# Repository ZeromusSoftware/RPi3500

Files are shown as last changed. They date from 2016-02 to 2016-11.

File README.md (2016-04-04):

#[Adamant](http://adamant.ga) 

####*A small cluster of Rasperry Pi connected with Hadoop*

---
### *Because we are found of Camembert and Croissant, but Fish & Chips and Guinness too.*

1. **French** 
2. **English** [^2]

----
[^1]:**French Version**

### Qui Sommes Nous ?

Nous sommes une équipe de 4 élèves de PTSI du Lycée Jean Perrin à Marseille

 - Louis Bernon - *Génie Thermique - Conception*
 - Quentin Bergé - *Génie Electrique - Conception*
 - William Jackson - *Réseau - Données et Algorithmes Machine Learning*
 - Bastien Pederencino- *Réseau - Données et Algorithmes Machine Learning - Big Data*

### Notre Objectif

 Création d'un Data Center et Analyseur miniaturisé à l'aide de Raspberry Pi, géré à distance via une Interface Web.
 ---

### Les Domaines Abordés
--

#### Le Big Data
Notre Data Center n'est pas comme les autres, il est pourvu d'une capacité d'analyse de données rentrant dans le domaine du Big Data.

Pour de plus amples informations, rendez-vous dans la rubrique [Big Data](https://github.com/ZeromusSoftware/RPi3500/tree/master/big_data)

#### L'Interface Web
Pour interagir avec ce Data Center et étant donné qu'il est connecté à Internet, nous avons décidé de mettre en place une Interface Web qui sera présente sur notre site [Adamant](http://adamant.ga).  
Cela nous permettra de lui envoyer des commandes, de récupérer des résultats (etc). Maintes applications seront possibles.

Pour de plus amples informations, rendez-vous dans la rubrique [API Web](https://github.com/ZeromusSoftware/RPi3500/tree/master/apiweb)

#### Le Réseau

Nos différents RPi sont connectés entre eux et forment ainsi un Réseau. Il sert ainsi à l'interaction et la communication entre ces différents composants.

####Machine Learning
Le Machine Learning est la capacité d'apprentissage des algorithmes sur la base de connaissances acquises.   
Ces nouveaux algorithmes peuvent alors solver des problèmes autrefois qualifiés de complexes.
Nous travaillons alors sur la façon de mettre en place ceci dans notre Data Center.

#### Génie Thermique
Le Système comporte des éléments qui sont susceptibles de chauffer et une chaleur excessive les endommageraient prématurement.

 Alors nous nous devons de les maintenir à température acceptable, pour ce faire nous utiliserons des ventilateurs récupérés de PC et des dissipateurs thermique conçus expressement pour les RPis.
 
 Pour de plus amples informations, rendez vous dans la rubrique [Heat Control](https://github.com/ZeromusSoftware/RPi3500/tree/master/heat_control)

#### Génie Electrique
Nous devons alimenter notre Data center conformément aux caractéristiques des composants présents tels les RPi2 et RPiB+ ainsi que le Switch Ethernet et le système de refroidissement.

Aussi ce Data Center doit pouvoir continuer à fonctionner en cas de coupure prolongée de l'alimentation du réseau électrique, c'est pourquoi il sera doté de batteries.

Pour de plus amples informations, rendez-vous dans la rubrique [Power Supply](https://github.com/ZeromusSoftware/RPi3500/tree/master/power_supply)

#### Conception
 Nous concevons notre Data Center miniaturisé dans lequel sera présent tout notre système. Il sera réalisé de contreplaqué okoumé et comprendra une surface transparente en plexiglass. Sa forme peut-être apparentée à celle d'une tour de PC.
 
 Pour de plus amples informations, rendez vous dans la rubrique [Box Architecture](https://github.com/ZeromusSoftware/RPi3500/tree/master/Box%20architecture) 
 
--

### Technologies Utilisées
* [Raspberry Pi](https://www.raspberrypi.org)
* [Python](https://www.python.org)
* [Raspbian](http://raspbian-france.fr)
* [Hadoop](http://hadoop.apache.org)
* [Propulse](http://www.ppulse.fr/#!)
* Git
* [LaTeX](https://www.latex-project.org)
* [SolidWorks](http://www.solidworks.fr)
* [Fritzing](http://fritzing.org/home/)
* Iron Hawk
* [PHP/MySQL](http://php.net) - [HTML5/CSS3](https://www.w3.org/html/)

--

### Contacts

* Mail : zermomus.software@gmail.com
* [Adamant] (http://adamant.ga)
* [Zeromus Software] (bpedernecino.legtux.org)
* [Bastien Pederencino](https://www.linkedin.com/in/bpederencino?authType=name&authToken=ZWAr&trk=prof-proj-cc-name)
* [Quentin Bergé](http://twitter.com/bergequentin)

>Google and Harvard Business Review said "Data Scientist: The Sexiest Job of the 21st Century"

------
English [^3]

[^2]: To English Version Click on "2"

[^3]: English

--

###About Us

We are a team compose by 4 students from Jean Perrin's preparatory PTSI class in Marseille.

- Louis Bernon - *Thermal Engineering - Conception*
- Quentin Bergé - *Electrical Engineering - Conception*
- William Jackson - *Network - Data and Machine Learning Algorithms*
- Bastien Pederencino- *Network - Data and Machine Learning Algorithms - Big Data*

### Our Objective

To make a Data Center in miniature with Raspberry Pi, remotely managed by a web interface.

---

### Domains Touched

--

#### Big Data

Our Data Center can analyze data, in accord with Big Data domains.

For more informations, please consult [Big Data](https://github.com/ZeromusSoftware/RPi3500/tree/master/big_data) 

#### The Web Interface

To interact with this Data Center, we decide to set up a Web Interface on our website [Adamant](http://adamant.ga). It enables to sent instructions and retrieve results (etc). Many usage can be possible.

For more informations, please consult [API Web](https://github.com/ZeromusSoftware/RPi3500/tree/master/apiweb)

#### The Network

Ours Raspberry Pi are interconnected and make a Network. It serves the communication between these differents features.

#### Machine Learning 

Machine Learning Algorithms are engineered with a learning capacity. It enables to solve complex issues.
We work to make our Data Center compatible with these algorithms.

#### Thermal Engineering

Our System countains active features as RPi, they can overheat, and being damaged. Therefore, we have to survey them, and keep it under review. We use fans and heatsink.

For more information, please consult [Heat Control](https://github.com/ZeromusSoftware/RPi3500/tree/master/heat_control)

#### Electrical Engineering

We have to provide an electric alimentation to all of Data Center's features as RPi2, RPi B+, Ethernet Switch and fans.
Also, this system need to stay in working order even in a power failure case, therefore we can use battery.

For more information, please consult [Power Supply](https://github.com/ZeromusSoftware/RPi3500/tree/master/power_supply)  

#### Conception

We build our miniaturize Data Center with plywood panel and plexiglass. His shape can be assimilate as a tower PC.

For more informations, please consult [Box Architecture](https://github.com/ZeromusSoftware/RPi3500/tree/master/Box%20architecture) 

--

###Employed Technologies

* [Raspberry Pi](https://www.raspberrypi.org)
* [Python](https://www.python.org)
* [Raspbian](http://raspbian-france.fr)
* [Hadoop](http://hadoop.apache.org)
* [Propulse](http://www.ppulse.fr/#!)
* Git
* [LaTeX](https://www.latex-project.org)
* [SolidWorks](http://www.solidworks.fr)
* [Fritzing](http://fritzing.org/home/)
* Iron Hawk
* [PHP/MySQL](http://php.net) - [HTML5/CSS3](https://www.w3.org/html/)

--

### Contacts

* Mail : zermomus.software@gmail.com
* [Adamant] (http://adamant.ga)
* [Zeromus Software] (bpedernecino.legtux.org)
* [Bastien Pederencino](https://www.linkedin.com/in/bpederencino?authType=name&authToken=ZWAr&trk=prof-proj-cc-name)
* [Quentin Bergé](http://twitter.com/bergequentin)

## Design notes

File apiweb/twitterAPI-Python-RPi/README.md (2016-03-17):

#[Adamant](http://adamant.ga) 

## A system to link RaspberryPi with Twitter's API thanks to Python
   
 * @author   William Jackson
 * @license  GNU General Public License 2
 * @version  0.1.0
 * @link     http://github.com/ZeromusSoftware/RPi3500

--

### Issues to fix

* (Try and tell us)

--

### Contacts

* Mail : zermomus.software@gmail.com

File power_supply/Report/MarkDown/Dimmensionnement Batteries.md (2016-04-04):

#Dimmensionnement Batteries
---
###Préambule

Pour parer à l'éventualité de la coupure de courant EDF, il nous faut une seconde source d'alimentation afin d'assurer le fonctionnement en continu de notre Data Center. Nous planchons, comme cité [précedemment](https://github.com/ZeromusSoftware/RPi3500/blob/master/power_supply/Report/MarkDown/In%20Case%20Of%20Emergency.md), sur une autonomie de 3h soit 180 minutes.

###Choix des Batteries

Nous comptons utiliser des batteries Li-Ion ou Li-Po, très couramment utilisées dans les appareils électronique portatif. Néanmoins ces batteries sont exigeantes, il faudra les surveiller constamment en particulier lors des phases de recharge et de décharge.

Puisque nous utilisons deux circuits de deux tensions différentes, nous utiliserons deux "piles".

* l'une délivrant une tension de 5V
* l'autre délivrant une tension de 12V

###Sous Tension de 5V

Sous cette tension, nous alimenterons les 4 Raspberry Pi 2 et le Raspberry Pi B+.
Au cours de nos tests, la consommation maximale relevé à été de 0,55 Ampères.  

En prenant une marge de sécurité alors de 0,25 Ampères :

* 0,8 A x 5 RPi = **4 A**

Or nous souhaitons 3h d'autonomie :

 * Q = I x T 
 * 4 A x 3h = **12 A.h**

 Il nous faudra alors une batterie avec une capacité de 12 A.h et capable de délivrer un courant superieur à 4 A sous une tension continue de 5V.

###Sous Tension de 12V

Sous cette tension, nous alimenterons les 4 ventilateurs et le switch ethernet.

Selon les caractéristiques constructeurs, sous cette tension la batterie devra fournir un courant d'environ 2,5 Ampères en s'imposant une petite marge de sécurité de 0,25 Ampères.

Or nous souhaitons 3h d'autonomie aussi :

* Q = I x T
* 2,5 x 3 = **7,5 A.h**

	Il nous faudra alors une capacité de 7,5 A.h sous cette batterie délivrant une tension continue de 12V qui doit être capable de délivrer un courant de 2,5 A.

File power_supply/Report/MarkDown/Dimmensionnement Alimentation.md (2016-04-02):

#Dimmensionnement Alimentation
---

###Composition du Système

Notre Data Center se compose de plusieurs éléments consommant de l'énergie :

* 4 Raspberry Pi 2
* 1 Raspberry Pi B+
* 1 Switch Ethernet
* 4 Ventilateurs

###Spécifications Constructeurs
Pour la partie Réseau et Informatique

* Raspberry Pi 2 : Il doit être alimenté en 5V avec un courant minimum de 1,8 A
* Raspberry Pi B+ : Il doit être alimenté en 5V avec un courant minimum de 0,7 A
* Switch Ethernet Netgear GS608 : Il doit être alimenté en 12V et consommme au maximum 0,5 A 

Pour la partie Refroidissement :

* 2 ventilateurs consommant 0,45 A chacun et alimenté en 12V
* 1 ventilateur consommant 0,7 A et alimenté en 12V
* 1 ventilateur consommant 0,16 A et alimenté en 12V

###Courant Nécéssaire

Nous pouvons établir le courant nécéssaire pour l'alimentation du système 

* Sur le 5V : 4 x 1,8 + 0,7 = **7,9A**
* Sur le 12V : 0,5 + 2 x 0,45 + 0,7 + 0,16 = **2,26A**

###Solution Apportée
 Nous avons récupéré une alimentation de PC 500W. Ces générateurs sont destinés à alimenter des composants éléctroniques fragiles, elle sera donc particulièrement bien adapté à l'alimentation de notre Data Center.
 
 De plus selon ses caractéristiques, elle peut fournir :
 
 * Sur le 5V : **36A**
 * Sur le 12V : **20A**

Elle est donc largement dimmensionnée pour notre système et lui permettra de nombreuses évolutions.

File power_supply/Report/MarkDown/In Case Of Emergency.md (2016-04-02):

#In Case Of Emergency
----
###Rupture d'Alimentation

Dans le cadre de l’alimentation du Data Center, il est nécessaire de se parer à toutes les situations. La pire étant celle d’une rupture d’alimentation du réseau EDF qui nous alimente par une tension de 230V et 50Hz.

Ainsi, notre Data Center doit pouvoir fonctionner sans interruption et ce normalement, pendant une panne d’électricité provenant de l’extérieur de l’enceinte. Alors nous devons le pourvoir d’une capacité de stockage d’énergie grâce à des batteries.

###Durée Moyenne d'une Panne Electrique

D’abord nous nous sommes renseignés sur la durée moyenne d’une panne de courant : Elle est d’environ 87,6 min entre 2010 et 2014 (dernières données disponibles selon EDF).

![Coupure EDF] (http://img15.hostingpics.net/pics/350350CoupureEDF.png "coupure edf")

###Durée d'Autonomie

Il est alors certain que nous devons avoir une durée supérieur et largement supérieur même pour parer à une éventuelle panne prolongée d’alimentation.

Nous plancherons ainsi sur une panne de 3H ce qui correspond à 180 min d’autonomie.

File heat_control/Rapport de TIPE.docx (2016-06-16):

Rapport de TIPE

Cette partie de la mise en place d’un data center vise au contrôle de la température des composants. Pour cela nous avons choisi un système de ventilation par soucis de praticité.

Nous avons mesuré la température des composants puis avons testé différentes dispositions des ventilateurs afin de trouver celle qui permettait de refroidir au mieux le boîtier. Après avoir obtenu ces « meilleures » dispositions, il faut trouver un compromis entre un bon refroidissement et les désavantages qu’impliquent ce système (consommation, bruit..).

Une fois le compromis trouvé, nous pourrons finir la construction du boîtier.

Mots-clés

Refroidissement – Ventilateurs – Raspberry pis – Empirique - Simulations

Cooling – Fans – Raspberry pis – Tests - Simulations

Bibliographie

-Site officiel de Fluke (http://www.fluke.com/fluke/frfr/thermographie/fluke-tis20.htm?pid=79860)

-Site d’information sur les Raspberry pis (http://the-raspberry.com/)

Remerciements

Je remercie l’équipe pédagogique qui nous a aidés et conseillés tout au long de l’année.

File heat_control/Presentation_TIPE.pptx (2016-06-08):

## TIPE : Mise en place d’un Data Center

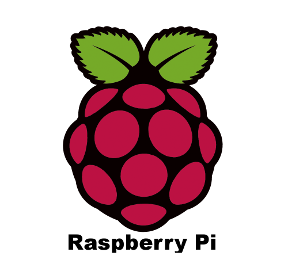
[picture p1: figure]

Louis Bernon – PTSI2

## Sommaire

I. Contrôle de la température
  1. Éléments à refroidir
  2. Mesures
  3. Moyens de refroidissement
  4. Dimensionnement
  5. Continuation
II. Conception du boitier
  1. Plans
  2. Dimensionnement
  3. Construction

## Contrôle de la température

Éléments à refroidir

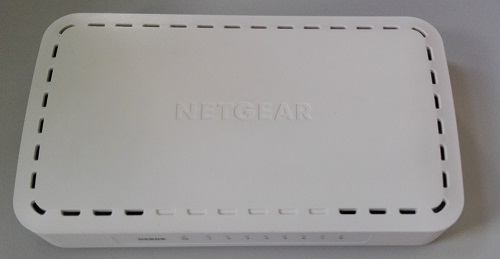
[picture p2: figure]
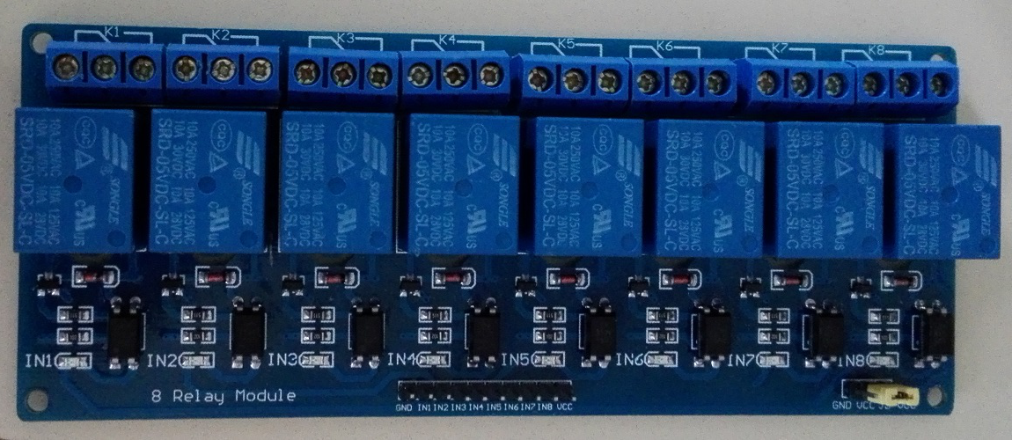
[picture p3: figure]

Switch Ethernet

Relais

Raspberry pi

## Mesures

On a simulé l’utilisation des Raspberrys grâce à une commande intégrée qui fait augmenter par paliers de 25% la charge du CPU
On a ensuite relevé les températures des cartes grâce à une caméra thermique Fluke lors de leur utilisation sans boîtier

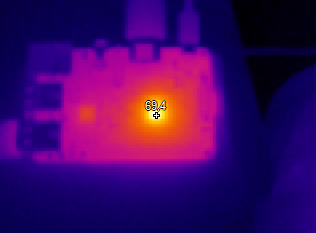
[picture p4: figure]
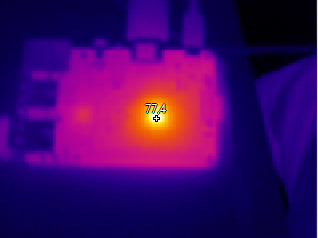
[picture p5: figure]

Utilisation optimale : température ambiante
La température est donc trop élevée pour une utilisation à plein temps

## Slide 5

Utilisation de radiateurs prévus spécialement pour les Raspberrys

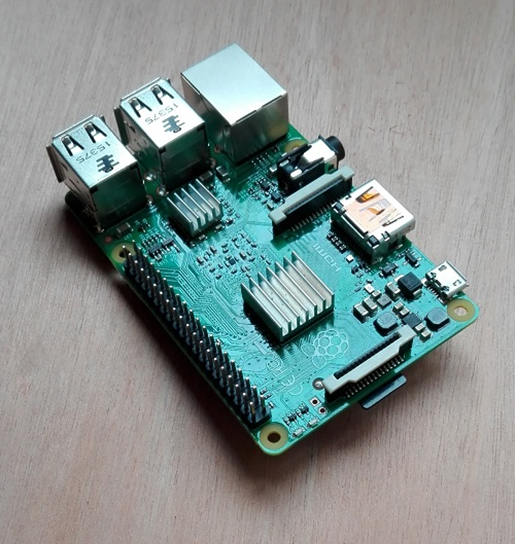
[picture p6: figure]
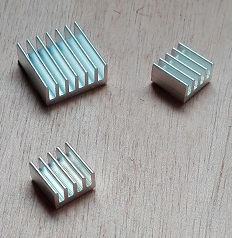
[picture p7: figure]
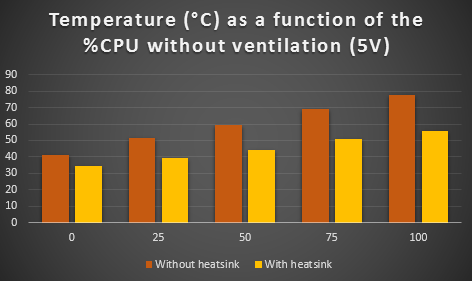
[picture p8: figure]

On perd jusqu’à 20°C avec les radiateurs mais la
Température est toujours trop élevée

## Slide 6

Nous avons donc ventilé les Raspberry et repris les températures pour différentes charges du CPU

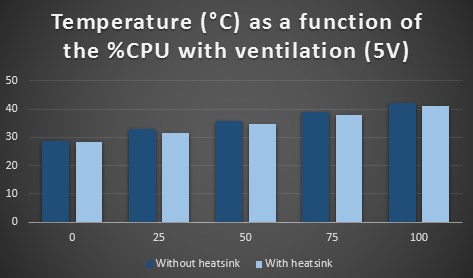
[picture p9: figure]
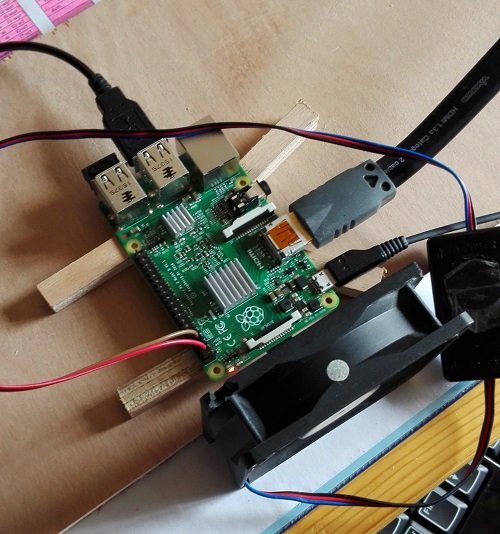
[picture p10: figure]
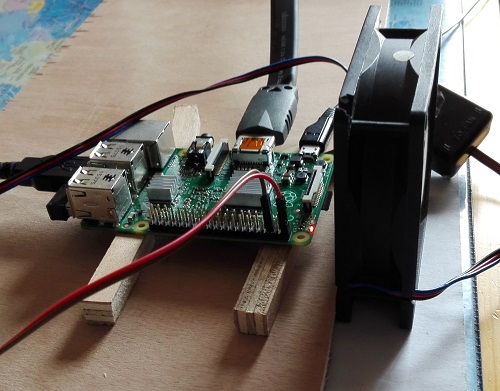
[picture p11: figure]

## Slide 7

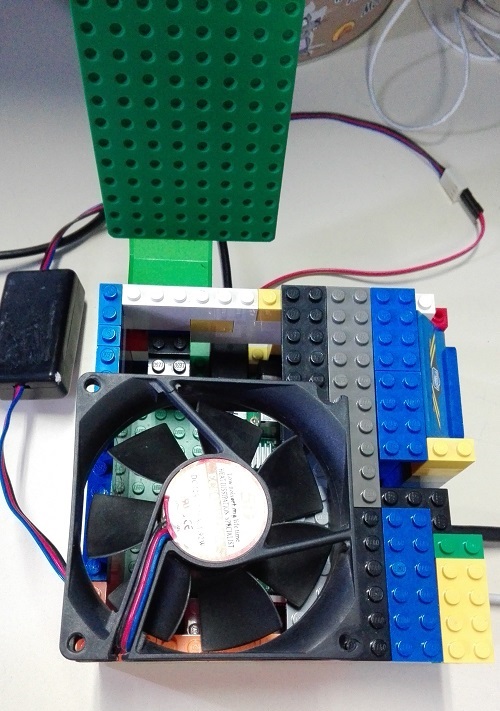
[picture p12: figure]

Utilisation finale des Raspberry pi dans un boîtier
On a donc fait les mêmes tests mais dans un boîtier

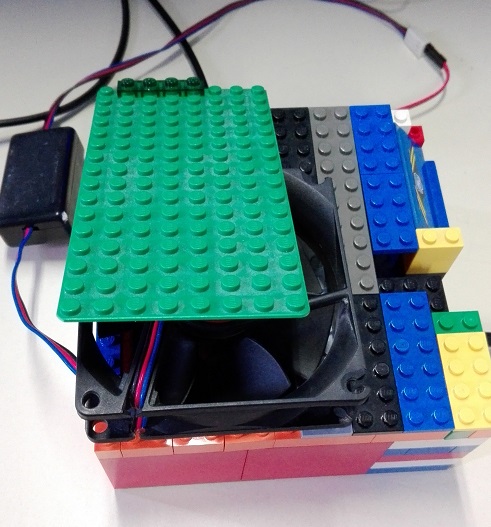
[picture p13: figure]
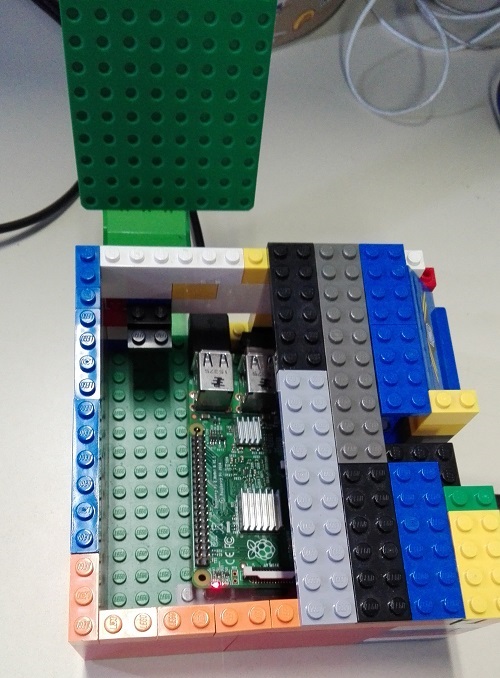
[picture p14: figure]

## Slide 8

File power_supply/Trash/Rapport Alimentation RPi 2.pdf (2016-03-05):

Quentin Bergé | 4 mars 2016

Préambule
Suite à nos tests de la semaine dernière, nous avons continué nos recherches et sommes parvenus à notre but final ! Nous avons pousser nos bêtes dans leurs derniers retranchement, et cela afin de mesurer la consommation de nos Rapsberry Pi 2

Principe de Mesure
Nous avons donc effectuer un Stress Test, communément appelé ainsi. Cela consiste en utilisant à 100% la puissance fourni par nos petits RPi2. Pendant ce temps, nous avons mesuré la consommation électrique de ces petites bébêtes.

Mode Opératoire Détaillé
A l’aide d’une ligne de commande entré dans le terminal des Pi sous raspbian, nous pouvons augmenter par palier de 25% la charge du CPU (Processeur). Dans ce cas nous avons pu effectué nos mesures à l’aide d’un ampèremètre branché en série du circuit d’alimentation.
En parallèle nous refroidissions aussi le processeur à l’aide d’un ventilateur, afin de ne pas le faire surchauffer, ce qui pourrait l’endommager prématurément.

Mesures

Charge CPU | Consommation (A) | Température (°C)
0 % | 0,260 | 22,1
25 % | 0,283 | 25
50 % | 0,318 | 26,1
75 % | 0,355 | 28,2
100 % | 0,395 | 29,3
Consommation RPi2 | 1

# STRESS TEST

### Consommation Raspberry Pi 2

Quentin Bergé | 4 mars 2016

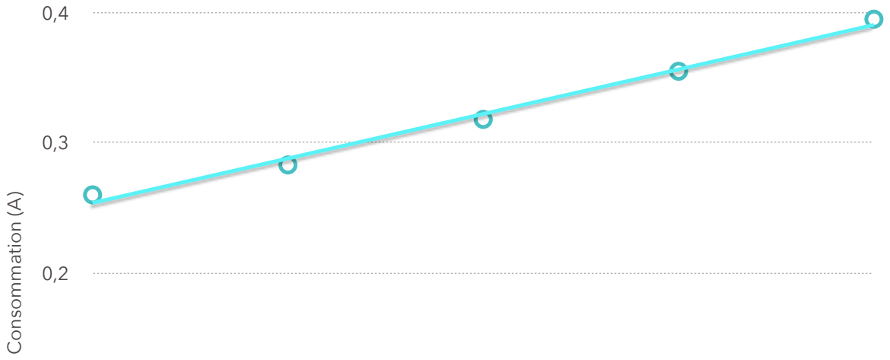
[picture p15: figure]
Consommation (A)

Consommation RPi2 | 2

Consommation Electrique en fonction Charge Processeur

0

0,1

Charge CPU (%)

0 | 0,25 | 0,5 | 0,75 | 1

Analyse Des Mesures
Cela est pour le moins déconcertant mais le RPi2 ne consomme pas plus de 0,4 A contrairement aux caractéristiques données par la Raspberry Pi Foundation qui préconise une alimentation de 1,8 A minimum.
Néanmoins ce qui est positif pour nous c’est qu’ainsi, le courant d’alimentation ne devra point être très important sur l’ensemble du système. Ainsi nous aurons besoin que de cables dimensionnées pour faire passer tout au plus 1 A sous 5V. Ce qui implique un coût bien moindre et donc largement maitrisé.

Conclusion
Nous avons ainsi pu conclure sur la consommation bien plus faible qu’indiqué pour nos petits RPi et ce même à pleine puissance, Alors notre alimentation pourra aisément alimenter l’ensemble de notre sytème et bien plus !

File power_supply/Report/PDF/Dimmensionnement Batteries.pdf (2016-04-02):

Pour parer à l'éventualité de la coupure de courant EDF, il nous faut une seconde source d'alimentation afin d'assurer le fonctionnement en continu de notre Data Center. Nous planchons, comme cité précedemment, (https://github.com/ZeromusSoftware/RPi3500/blob/master/power_supply/Report/MarkDown/In%20Case%20Of%20Emergency.md) sur une autonomie de 3h soit 180 minutes.

Nous comptons utiliser des batteries Li-Ion ou Li-Po, très couramment utilisées dans les appareils électronique portatif. Néanmoins ces batteries sont exigeantes, il faudra les surveiller constamment en particulier lors des phases de recharge et de décharge.

Puisque nous utilisons deux circuits de deux tensions différentes, nous utiliserons deux "piles".

l'une délivrant une tension de 5V
l'autre délivrant une tension de 12V

Sous cette tension, nous alimenterons les 4 Raspberry Pi 2 et le Raspberry Pi B+. Au cours de nos tests, la consommation maximale relevé à été de 0,5 Ampères.

En prenant une marge de sécurité alors de 0,1 Ampère :

0,6 A * 5 RPi = 3,5 A

Or nous souhaitons 3h d'autonomie :

Q = I*T
3,5 A * 3h = 10,5 A.h

Il nous faudra alors une batterie avec une capacité de 10,5 A.h et capable de délivrer un courant superieur à 3,5 A sous une tension continue de 5V.

Sous cette tension, nous alimenterons les 4 ventilateurs et le switch ethernet.

Selon les caractéristiques constructeurs, sous cette tension la batterie devra fournir un courant d'environ

# Dimmensionnement Batteries

## Préambule

## Choix des Batteries

## Sous Tension de 5V

## Sous Tension de 12V

2,5 Ampères en s'imposant une petite marge de sécurité de 0,25 Ampères.

Or nous souhaitons 3h d'autonomie aussi :

Q = I*T
2,5 * 3 = 7,5 A.h

Il nous faudra alors une capacité de 7,5 A.h sous cette batterie délivrant une tension continue de 12V qui doit être capable de délivrer un courant de 2,5 A.

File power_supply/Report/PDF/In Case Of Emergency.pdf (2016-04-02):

Dans le cadre de l’alimentation du Data Center, il est nécessaire de se parer à toutes les situations. La pire étant celle d’une rupture d’alimentation du réseau EDF qui nous alimente par une tension de 230V et 50Hz.

Ainsi, notre Data Center doit pouvoir fonctionner sans interruption et ce normalement, pendant une panne d’électricité provenant de l’extérieur de l’enceinte. Alors nous devons le pourvoir d’une capacité de stockage d’énergie grâce à des batteries.

D’abord nous nous sommes renseignés sur la durée moyenne d’une panne de courant : Elle est d’environ 87,6 min entre 2010 et 2014 (dernières données disponibles selon EDF).

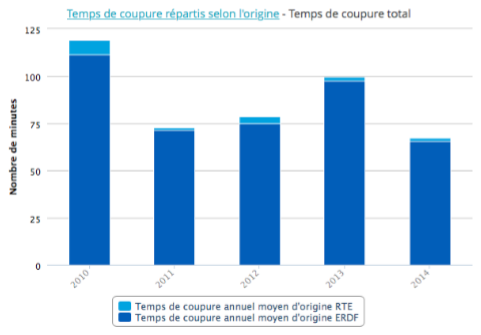
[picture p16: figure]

Il est alors certain que nous devons avoir une durée supérieur et largement supérieur même pour parer à une éventuelle panne prolongée d’alimentation.

Nous plancherons ainsi sur une panne de 3H ce qui correspond à 180 min d’autonomie.

# In Case Of Emergency

## Rupture d'Alimentation

## Durée Moyenne d'une Panne Electrique

## Durée d'Autonomie

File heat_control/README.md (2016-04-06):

# Welcome in Heat Control

This part of the **Adamant** project is dedicated to the refreshment of the box that will contain every part of this project.
Here will be exposed our equipment and our progress in the achievement of this part.

We'll have to run a lot of tests in order to determine the best and the greenest way to refresh the box.

----------------

If you're interested with the box I talked about, you can see it [here](<https://github.com/ZeromusSoftware/RPi3500/tree/master/box_architecture>)

----------------
**If you have some suggestions to make, contact me at [Louis Bernon](mailto:loulou.bernon@gmail.com)**

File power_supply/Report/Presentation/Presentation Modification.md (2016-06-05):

#Changement pour Présentation

###Mesures
* Détailler le protocole de mesure
* Parler du redresseur de l'alimentation
* Parler de l'abaissement de tension 
* Faire apparaitre les bornes sur la mesures COM et A

###Schémas
* Détailler plus les schémas
* Montrer de meilleures photos

###Durée
* Faire plus concis selon Minetti, on dépasse trop là durée

###Conclusion
* Elaborer une conclusion à proprement parler sur le respects de la satisfaction du critère d'alimentation

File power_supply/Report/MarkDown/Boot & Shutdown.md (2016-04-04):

#Boot & Shutdown
---

###Préambule

Afin de bien dimmensionner nos batteries et notre alimentation, nous recherchons toujours la consommation maximale de nos Raspberry. Ainsi, c'est dans ce cadre que s'inscrit ce rapport. Nous avons alors eu l'idée de mesurer la consommation de nos mini-ordinateurs dans des phases critiques.

###Principe de Mesure

La phase d'allumage est critique au sens où le Pi se doit de disposer de tout sa puissance afin de se mettre en route, de tester le fonctionnement de tout ses composants. C'est ici que l'on pourrait atteindre un pic de consommation.	

La phase d'extinction est quant à elle importante afin de constater la consommation du Pi quand il est éteint.

Nous mesurerons alors la consommation de notre Pi lors de ces deux phases.

###Mode Opératoire Détaillé

Nous brancherons en série du circuit d'alimentation un Ampèremetre qui nous afficheras alors la consommation instantanée du RPi.

Nous restranscrirons toutes nos mesures sous forme de graphiques que nous analyserons.

###Mesures
--

1. Démarrage

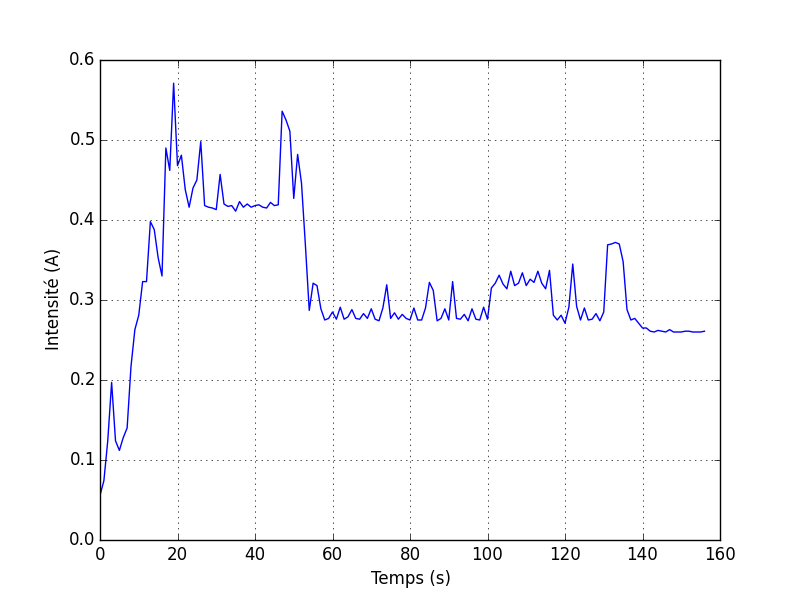
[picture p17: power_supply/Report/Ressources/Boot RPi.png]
Boot
 

2. Extinction

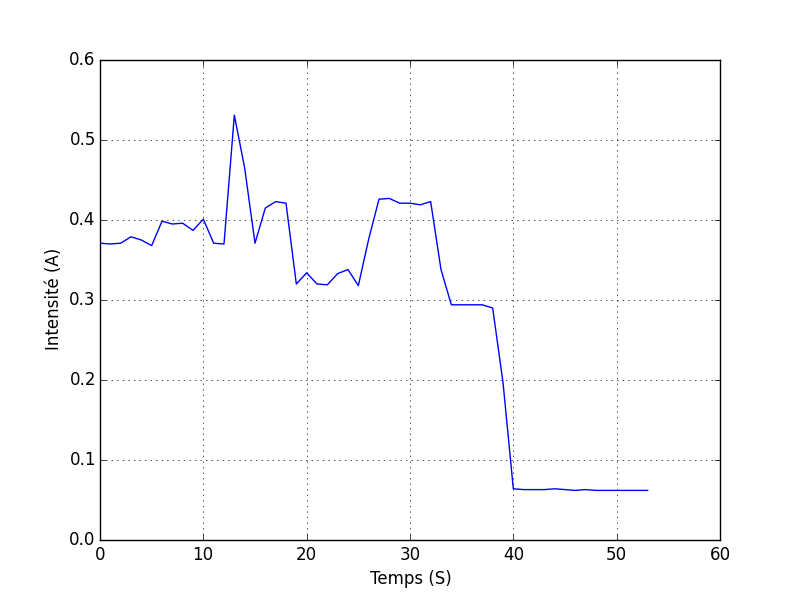
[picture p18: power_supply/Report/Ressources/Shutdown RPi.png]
Shutdown


###Analyse des Courbes
--

#####Démarrage

* Nous pouvons d'abord voir un pic à 0,58 Ampères ce qui est la plus haute valeur constatée jusqu'à présent.
* La phase de démarrage dure, avant que tout soit prêt à fonctionner, environ une minute ce qui correspond à la fin du dernier pic de consommation sur la courbe.
* Aussi nous pouvons noter la stabilisation de la consommation au bout d'environ 145 secondes.

#####Extinction

* La phase d'extinction dure environ 40 secondes.
* Nous pouvons observer un pic à plus de 0,530 Ampères, ensuite le courant décroit à nouveau puis un nouveau pic à 10 secondes de la fin de la phase puis presque le silence radio, le Pi à rendu son dernier souffle.
* En étant éteint, notre Raspberry consomme tout de même près de 60 mA ce qui parait assez élevé.

###Conclusion

Le pic de consommation confirme alors nos hypothèses, le RPi consomme le plus de courant durant sa phase d'allumage. Il faudra alors calquer nos dimmensionnement de nos alimentations sur ces résultats.
	
Aussi il paraît encore et toujours très peu gourmand en énergie, moins de 3 Watts de puissance consommé ce qui en constitue un parfait équipement pour rester allumer en permanence tel un Data Center.

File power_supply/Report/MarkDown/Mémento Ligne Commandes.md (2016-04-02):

#Mémento Ligne Commandes

* Augmenter Cadence CPU /25%

		sudo yes >/dev/null &
	
* Revenir à la Normale

		sudo killall yes
		
* Connaître Température CPU

		/opt/vc/bin/vcgencmd measure_temp

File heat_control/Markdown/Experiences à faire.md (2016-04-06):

# Mesure de la température

Afin de connaître la quantité de chaleur à refroidir, nous avons plusieurs tests à effectuer : 

* Mesure de la chaleur dégagée par un RPi à l'air libre avec/sans radiateur et avec/sans ventilation

* Mesure de la chaleur dégagée par un RPi dans un espace presque fermé avec/sans radiateur et avec/sans ventilation

* Mesure de la chaleur dégagée par plusieurs RPi dans un espace fermé de volume similaire à celui du boîtier final

* Test de différentes dispositions (placement des RPi entre eux, ventilateur...) afin de trouver la plus efficace et la plus écologique)

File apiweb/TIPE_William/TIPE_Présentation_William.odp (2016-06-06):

## Présentation TIPE

William Jackson

## Contexte & Exigences

Dans un projet de mise en place d'un mini data center portatif, on souhaite pouvoir intéragir avec l'ensemble à distance pour pouvoir controler le bon fonctionnement ou intervenir en cas de soucis.

Requirement Diagram

I – Le datacenter doit etre portable

II – Envoi de commandes avec

temps d'attente de réponse court (10s maxi)

III – Permet la visualisation de l'état du système :

composants allumés/éteints, température environnante

## Problématique

## Grands Axes

Comment communiquer à distance avec un data center portable ?

A – Le mode de communication

1) Le problème du serveur web

2) Les solutions envisagées

2) La solution Twitter

B – La communication côté site

1) l'IHM

2) la réception des messages

3) l'envoi des messages

C – La communication côté data center

1) la réception des messages

2) traitement des messages

3) l'intéraction avec les composants

## A – Le mode de communication

Il faut trouver un moyen de communiquer avec la machine

Diagramme d'utilisateur ?

## 1) Le problème de serveur web

A – Le mode de communication

## 2) Les solutions envisagées

A – Le mode de communication

## 3) La solution Twitter

A – Le mode de communication

## B – La communication côté site

## 1) L'Interface Homme Machine

B – La communication côté site

## 2) Le traitement des messages

B – La communication côté site

## 3) L'envoi des messages

B – La communication côté site

## C - La communication côté data center

## 1) La réception des messages

B – La communication côté data center

## 2) Le traitement des messages

B – La communication côté data center

## 3) L'intéraction avec les composants

B – La communication côté data center

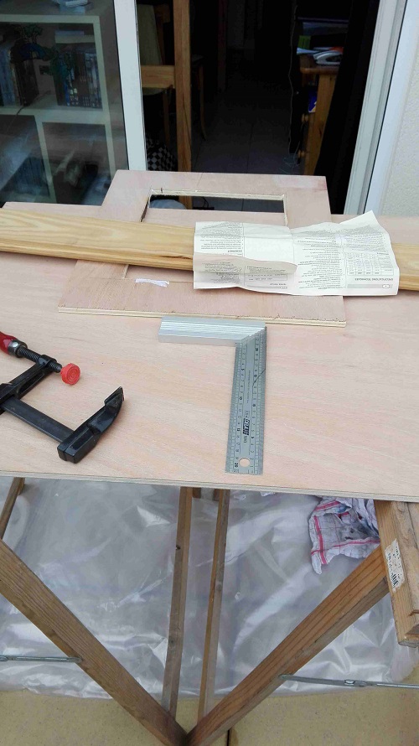
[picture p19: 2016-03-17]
box_architecture/Pictures/Cutting.jpg

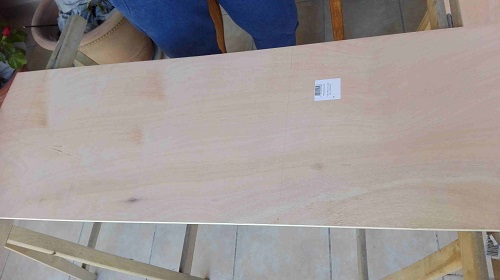
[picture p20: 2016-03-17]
box_architecture/Pictures/Plank2.jpg

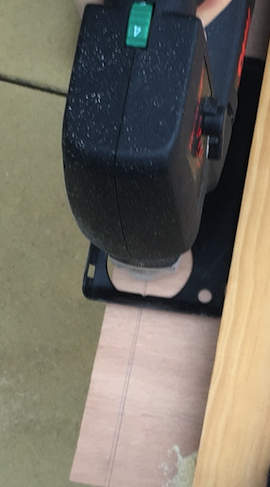
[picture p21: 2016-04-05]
box_architecture/Pictures/Scie Sauteuse en Action.png

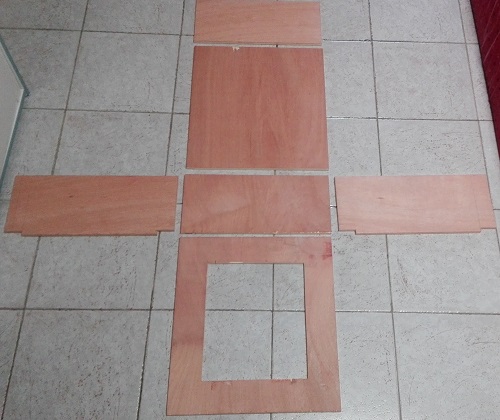
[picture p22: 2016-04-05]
box_architecture/Pictures/Planks.jpg

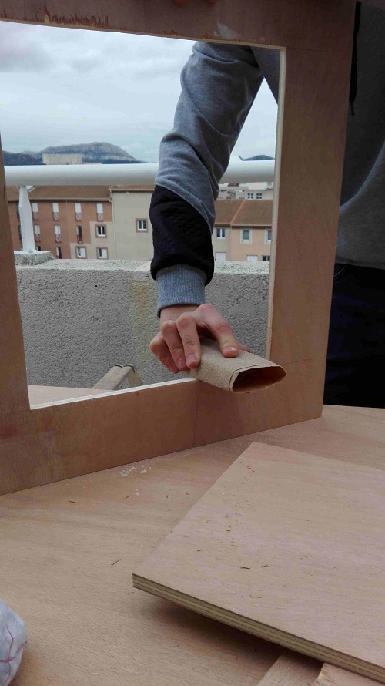
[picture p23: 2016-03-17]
box_architecture/Pictures/sanding.jpg

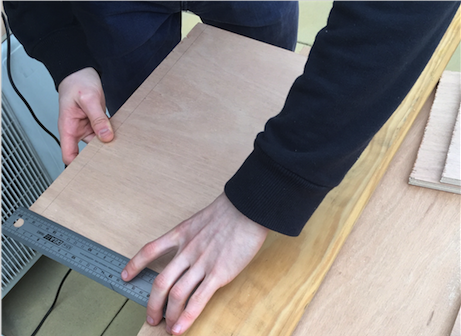
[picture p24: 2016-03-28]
box_architecture/Pictures/Mesure ecartement Equerre.png

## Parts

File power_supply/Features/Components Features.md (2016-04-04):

# Caractéristiques Composants
---

###Raspberry Pi

| | Model B+ | Model 2B |
|:---|---|---:|
| SoC | Broadcom BCM2835 | Broadcom BCM2836 |
| CPU |700 MHz ARM11 Single Core |900 Mhz ARM Cortex-A7 Quadri Core|
| GPU | Broadcom VideoCore IV  | Broadcom VideoCore IV |
| SDRAM | 512 Mo | 1 Go |
|Nominal Power | 3 W (600mA) | 4 W (800mA) |

###Switch Netgear
| Model | GS608 |
|:---:|:---:|
|Consommation Max|4,32 W|
|T° Fonctionnement Max| 40°C|

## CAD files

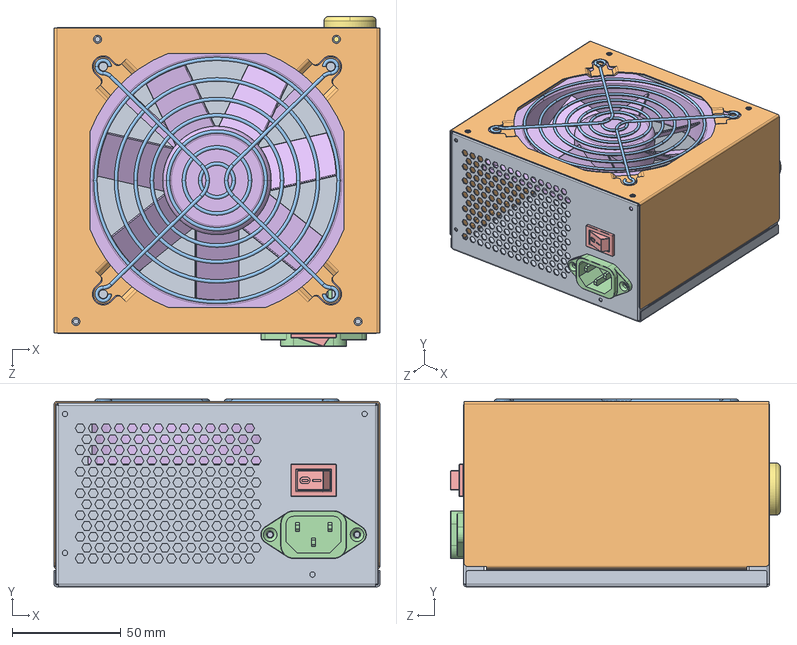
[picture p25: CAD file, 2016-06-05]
box_architecture/Modeler Solid Works/Boite 1st Jet/Models Utils/ATX Power Supply v1.0.SLDASM
150.0 x 86.4 x 152.0 mm
Box v1.0 - ATX Power Supply
Cover v1.0 - ATX Power Supply
Grelha Prot Vent 120
IEC Plug
Switch on-off
Ventax 119x119x26
Casq

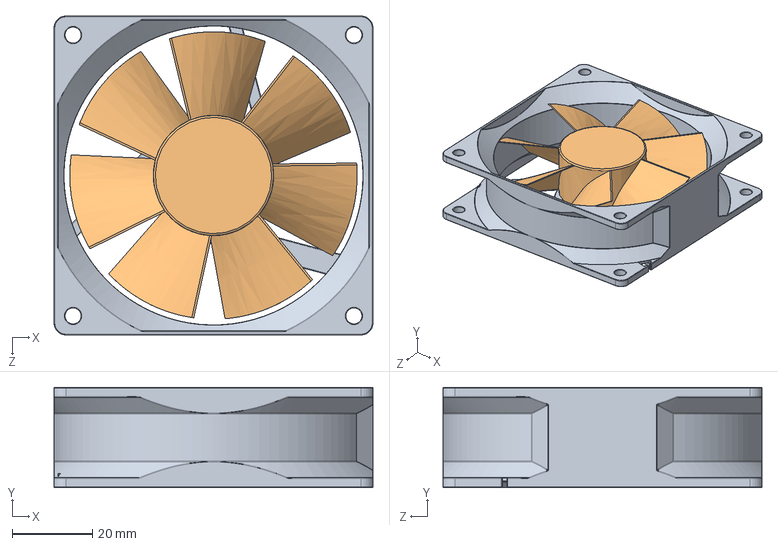
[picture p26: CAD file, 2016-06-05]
box_architecture/Modeler Solid Works/Boite 2nd Jet et Finale/80mm Fan/80MM_FAN/80MM_FAN_ASSEM.SLDASM
79.5 x 25.0 x 79.5 mm
80MM_FAN_HOUSING
80MM_FAN_PROP

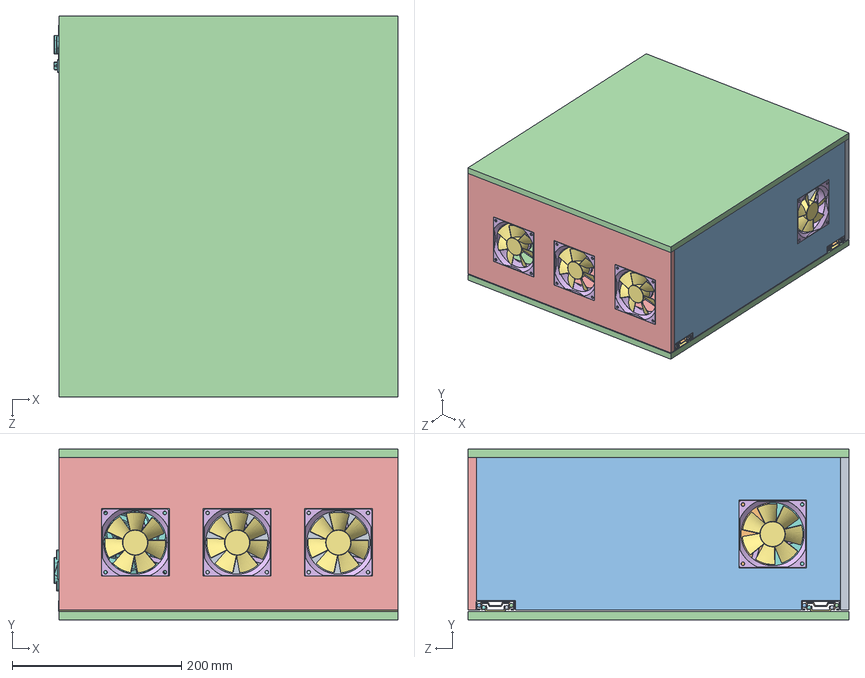
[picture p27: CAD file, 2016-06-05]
box_architecture/Modeler Solid Works/Boite 2nd Jet et Finale/Assemblage Boite Finale.SLDASM
406.0 x 201.4 x 450.0 mm
Plaque Bas 20,40
Plaquecoté gauche 18,43
Plaque coté 18,43
Plaque Derriere 40,45
Plaque Dessus 20,40 Percée Ventilo
80MM_FAN_HOUSING x 4
80MM_FAN_PROP x 4
ATX Power Supply v1.0
Plaque Percée Cote
Piece de Plexi

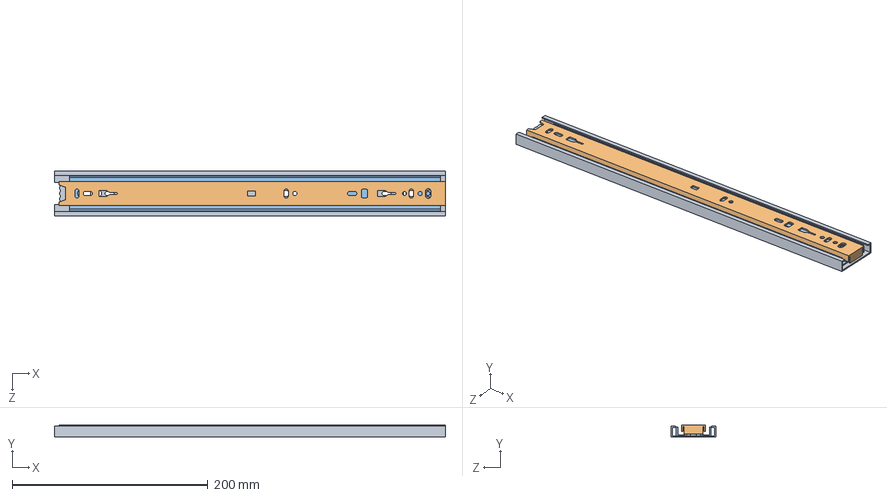
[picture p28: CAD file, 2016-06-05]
box_architecture/Modeler Solid Works/Boite 2nd Jet et Finale/Coulisse Bille Sortie Totale 400mm/39-225-400/39-225-400.SLDASM
400.0 x 12.7 x 45.7 mm

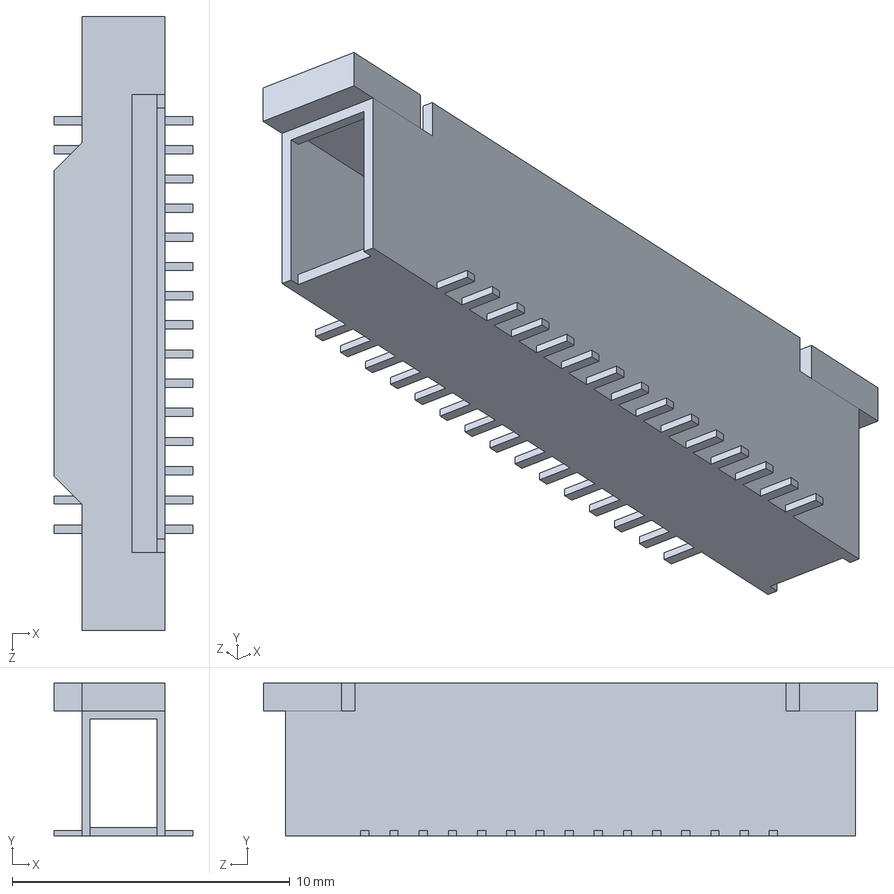
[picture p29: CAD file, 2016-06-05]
box_architecture/Modeler Solid Works/Boite 2nd Jet et Finale/Raspberry/Raspberry Pi 2/CameraAssembly.SLDPRT
5.00 x 5.50 x 22.1 mm

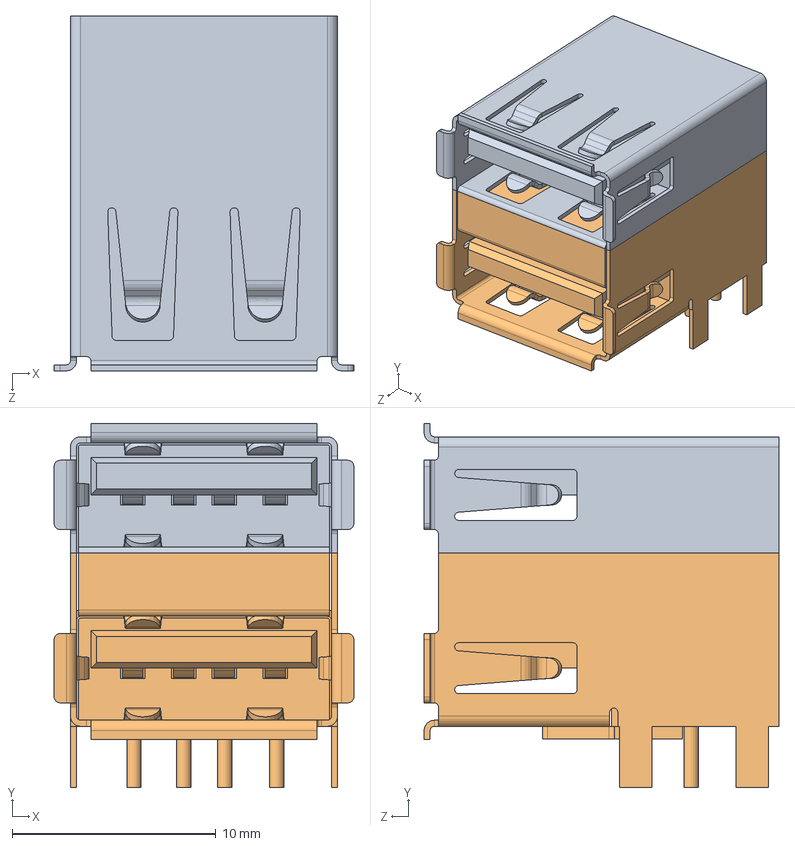
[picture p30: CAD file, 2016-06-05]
box_architecture/Modeler Solid Works/Boite 2nd Jet et Finale/Raspberry/raspberry-pi-model-b-2/raspberry_pi_B+_(USB_x2).SLDASM
14.7 x 17.9 x 17.4 mm
raspberry_pi_B+_(USB_x2_part1)
raspberry_pi_B+_(USB_x2_part2)

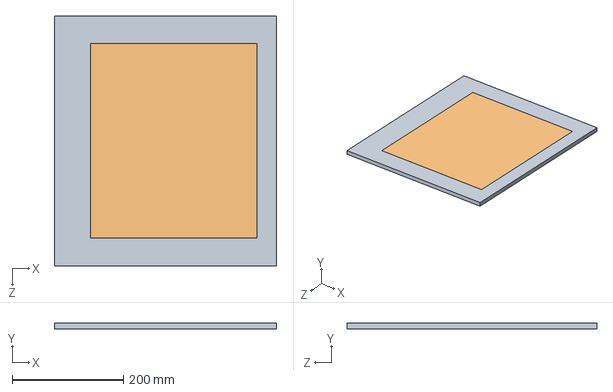
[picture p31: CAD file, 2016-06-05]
box_architecture/Modeler Solid Works/Boite 2nd Jet et Finale/Pièce Coté Avec Plexi.SLDASM
400.0 x 10.0 x 450.0 mm
Plaque Percée Cote
Piece de Plexi

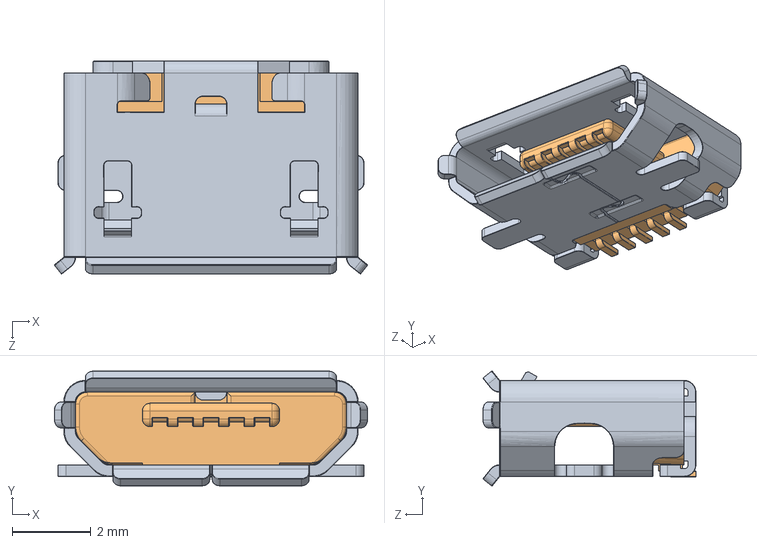
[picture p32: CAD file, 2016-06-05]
box_architecture/Modeler Solid Works/Boite 2nd Jet et Finale/Raspberry/raspberry-pi-model-b-2/raspberry_pi_B+_(micro_USB).SLDASM
7.97 x 2.92 x 5.43 mm
raspberry_pi_B+_(micro_USB_cover)
raspberry_pi_B+_(micro_USB_contacts)

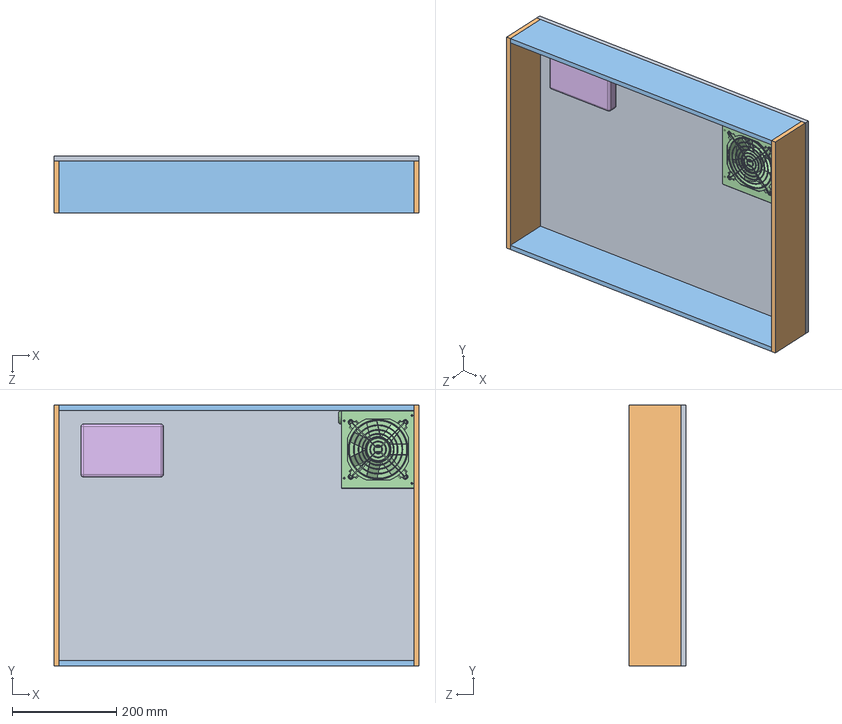
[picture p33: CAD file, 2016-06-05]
box_architecture/Modeler Solid Works/Boite 1st Jet/Boite Finale.SLDASM
700.0 x 500.0 x 110.0 mm
Plaque Base 70,50
Plauqe 50,10 x 2
Plauqe 70,10 x 2
ATX Power Supply v1.0
Switch Ethernet

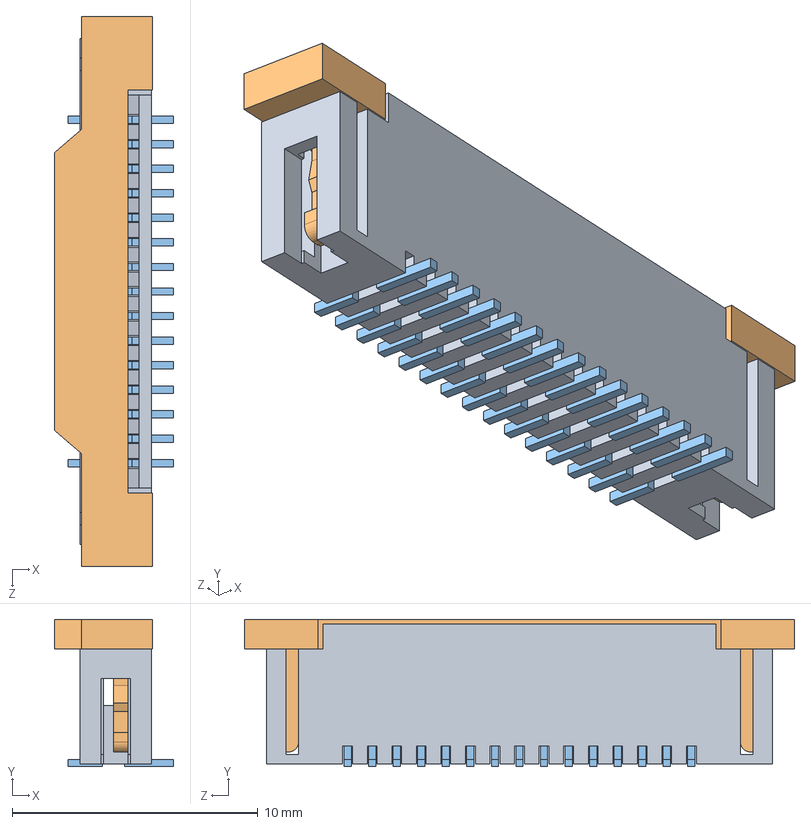
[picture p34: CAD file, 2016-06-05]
box_architecture/Modeler Solid Works/Boite 2nd Jet et Finale/Raspberry/raspberry-pi-model-b-2/raspberry_pi_B+_(15_pin_FFC_Connector).SLDASM
4.85 x 6.00 x 22.4 mm
raspberry_pi__15_pin_FFC_Connector_body
raspberry_pi__15_pin_FFC_Connector_locker
raspberry_pi__15_pin_FFC_Connector_pins x 15

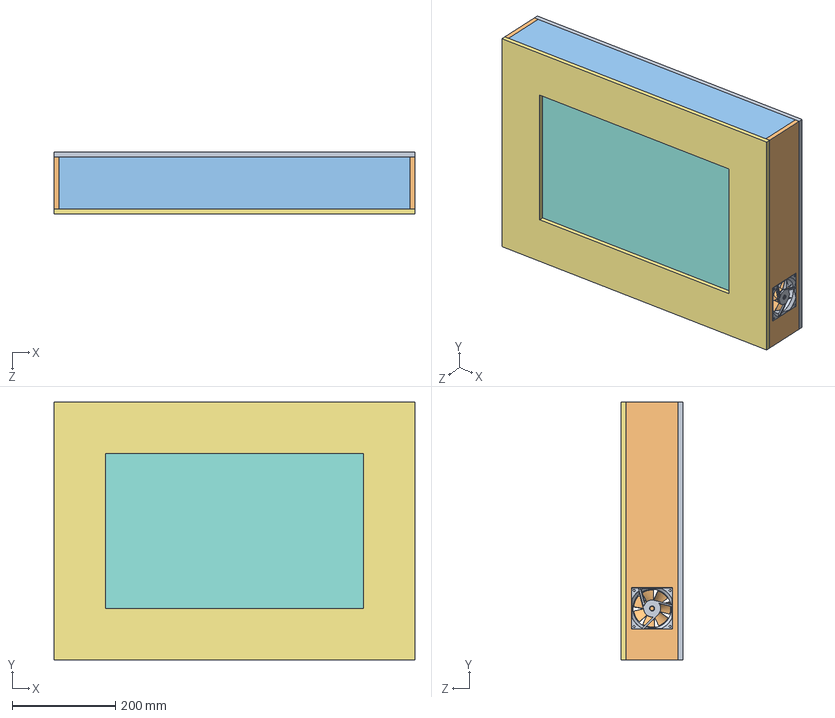
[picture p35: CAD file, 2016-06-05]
box_architecture/Modeler Solid Works/Boite 1st Jet/Boite 1st.SLDASM
700.0 x 500.0 x 120.0 mm
Plaque Base 70,50
Plauqe 50,10 x 2
Plauqe 70,10 x 2
ATX Power Supply v1.0
Switch Ethernet
Plaque Dessus 1rst 70,50
Plexiglase 1st
80MM_FAN_HOUSING
80MM_FAN_PROP

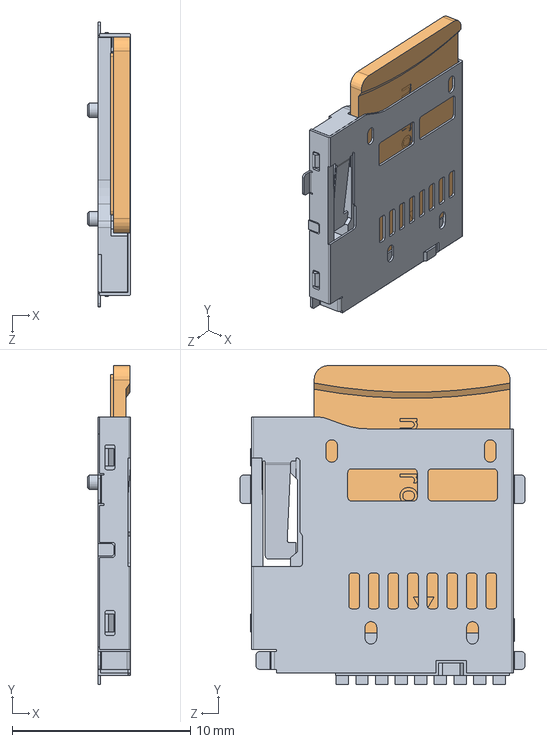
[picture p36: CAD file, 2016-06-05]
box_architecture/Modeler Solid Works/Boite 2nd Jet et Finale/Raspberry/raspberry-pi-model-b-2/raspberry_pi_B+_(microsd_slot).SLDASM
2.44 x 17.9 x 16.0 mm
raspberry_pi_B+_(slot)
raspberry_pi_B+_(microsd)

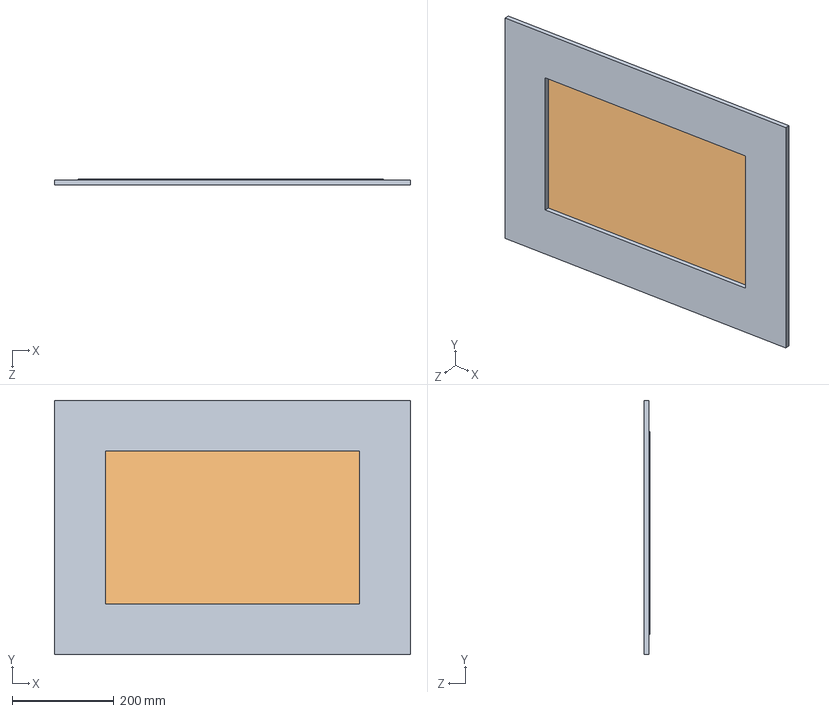
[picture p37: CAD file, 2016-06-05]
box_architecture/Modeler Solid Works/Boite 1st Jet/Plaque Dessus Assemblage 1st.SLDASM
700.0 x 500.0 x 12.0 mm
Plaque Dessus 1rst 70,50
Plexiglase 1st

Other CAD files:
box_architecture/Modeler Solid Works/corsair-power-supply-units-1/RM750 SMPS.SLDASM
box_architecture/Modeler Solid Works/Boite 1st Jet/80mm-fan--1/80MM_FAN/80MM_FAN_ASSEM.SLDASM
box_architecture/Modeler Solid Works/Boite 2nd Jet et Finale/80mm Fan/80MM_FAN 2/80MM_FAN_ASSEM.SLDASM
box_architecture/Modeler Solid Works/Boite 2nd Jet et Finale/Coulisse Bille Sortie Totale 400mm/39-222-400/39-222-400.SLDASM
box_architecture/Modeler Solid Works/Boite 1st Jet/40754/40754.SLDPRT
box_architecture/Modeler Solid Works/Boite 1st Jet/46482/46482.SLDPRT
box_architecture/Modeler Solid Works/Boite 1st Jet/80mm-fan--1/80MM_FAN.stl
box_architecture/Modeler Solid Works/Boite 1st Jet/80mm-fan--1/80MM_FAN/80MM_FAN_HOUSING.SLDPRT
box_architecture/Modeler Solid Works/Boite 1st Jet/80mm-fan--1/80MM_FAN/80MM_FAN_PROP.SLDPRT
box_architecture/Modeler Solid Works/Boite 1st Jet/80mm-fan--1/80MM_FAN_ASSEM.IGS
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

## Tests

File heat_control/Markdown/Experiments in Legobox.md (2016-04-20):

# Experiments in the Legobox

##### With two ventilators :
  * One in the front and one in back
  * One in the front and one on top (with and without hole(s) in the back)
  * Two in the front (with littles holes/big hole in back)

 ---------------  

##### With three ventilators :
  * Two in the front and one in back
  * One in the front and two on top (with and without hole(s) in back)
  * One in every place (front, top and back)
  * One in front, one in the box (blowing toward), one in back
  * One in front, one in the box (blowing toward), one on top

-----------------

##### With four ventilators :
  * One in front and three on top (with and without hole(s) in back)
  * One in front, one in back and two on top
  * One in front, one in the box (blowing toward), and two on top

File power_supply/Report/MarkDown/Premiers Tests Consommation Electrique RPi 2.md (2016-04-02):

#Premiers Tests Consommation Electrique Raspberry Pi 2
****

##Consommation Théorique

* La [Raspberry Pi Foundation](https://www.raspberrypi.org) préconise une alimentation minimale de 1,8 A. Comme tout bon étudiant scientifique, j'ai cherché à coroborer ces dires.

##Mesures

###Principe de Mesure

J'ai effectué ces mesures avec un Ampèremètre en série du circuit d'alimentation et du RPi. On module la charge CPU en lançant des applications plus ou moins gourmande en ressources.

### Résultats
	
| CPU Load (%) | Courant Consommé (A) |
| ---| ---:  |
| 2% | 0,260 |
| 26% | 0,308 |
| No Data | 0,602 |

##Analyse
	
* L'état “No Data“ correspondait au premier allumage de notre RPi, quand il n'y avait pas d'OS installé.
* L'augmentation d'une charge processeur de 24% n'emploie que 0,05 A de plus.
* Le Raspberry consomme très peu, on relève ici un courant maximale de 0,3 A en utilisation.

## Conclusion

Nos tests révèlent que le Raspberry est un appareil très peu gourmand en énergie, consommation inferieure ou égal à 3 Watts. Il apparaît aussi que nous sommes encore bien loin des 1,8 A annoncés par la Raspberry Pi Foundation.  
Afin d'augmenter sensiblement la consommation, nous pousserons cette carte au maximum de ses capacitées en essayant d'encoder une vidéo en Full HD par exemple, ou alors de provoquer ceci par des lignes de commandes.

*To be continued*

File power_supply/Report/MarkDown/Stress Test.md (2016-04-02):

#Stress Test
---
###Préambule

Suite à nos tests de la semaine dernière, nous avons continué nos recherches et sommes parvenus à notre but final ! Nous avons pousser nos bêtes dans leurs derniers retranchements, cela afin de mesurer la consommation maximale de nos Rapsberry Pi 2.

###Principe de Mesure 

Nous avons donc effectué un Stress Test, communément appelé ainsi. Cela consiste en utilisant à 100% la puissance fourni par nos petits RPi2. Pendant ce temps, nous avons mesuré la consommation électrique de ces petites bébêtes.

###Mode Opératoire Détaillé

A l’aide d’une ligne de commande entré dans le terminal des Pi sous raspbian, nous pouvons augmenter par palier de 25% la charge du CPU (Processeur). 

	 yes > /dev/null&

Dans ce cas nous avons pu effectué nos mesures à l’aide d’un ampèremètre branché en série du circuit d’alimentation.

En parallèle nous refroidissions aussi le processeur à l’aide d’un ventilateur, afin de ne pas le faire surchauffer, ce qui pourrait l’endommager prématurément.

###Mesures

| Charge CPU (%) | Consommation (A) | 
| :--- | :---: |
| 0 % 		 |	 0,260 |
| 25 % | 0,283 | 
| 50 % | 0,318 | 
| 75% | 0,355 |
| 100% | 0,395 |

Nous pouvons alors extraire une courbe presque linéaire :

Consommation Electrique f() Charge Processeur

###Analyse Des Mesures

Cela est pour le moins déconcertant mais le RPi2 ne consomme pas plus de 0,4 A contrairement aux caractéristiques données par la Raspberry Pi Foundation qui préconise une alimentation de 1,8 A minimum.

La consommation est quasi proportionnelle à la charge processeur.

Néanmoins ce qui est positif pour nous c’est qu’ainsi, le courant d’alimentation ne devra point être très important sur l’ensemble du système. Ainsi nous aurons besoin que de cables dimensionnées pour faire passer tout au plus 2 A sous 5V. Ce qui implique un coût bien moindre et donc largement maitrisé.

###Conclusion

Nous pouvons ainsi conclure sur une consommation bien plus faible qu'indiqué pour nos petits RPi et ce même à pleine puissance, Alors notre alimentation pourra aisément alimenter l’ensemble de notre sytème et bien plus !

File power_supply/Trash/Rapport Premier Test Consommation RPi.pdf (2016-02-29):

### Rapport Premiers Tests Consommation Raspberry PI2

La Raspberry Pi foundation nous donne une consommation théorique maximale de 1,8 A par Raspberry Pi. Alors, en tout bon étudiant de classe scientifique j’ai cherché à corroboré cette affirmation.

Ainsi, voici mes premières analyses:

*: Cet état correspondait au premier allumage de notre Raspberry, quand il n’y avait pas encore d’Os sur la carte.

Il est intéressant de noter que le raspberry consomme très peu pour un usage CPU inférieur à 30%, encore bien loin des 1,8A annoncés par la fondation.
Aussi la variation entre une charge processeur de 24% n’emploie que 0,048 A de plus, ce qui parait peu.
De plus le RPi alors qu’il n’avait pas d’Os consommait bien plus que dans ces derniers cas. Il va être intéressant de creuser cette question.

Nous allons alors prochainement réaliser des test afin de pousser dans ses derniers retranchements la carte pour un usage CPU de 100%, pour cela nous pensions à un encodage d’une vidéo en 1080p

To be continued…

CPU Load (%) | Courant Consommé (A)
Pas de données* | 0,62
2 % | 0,260
26 % | 0,308

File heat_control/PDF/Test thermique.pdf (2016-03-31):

## Tests thermiques

Afin de connaître le meilleur moyen de refroidir nos raspberry pi une fois qu'ils seront dans le boîtier, nous allons tester la température dégagée par les Rpis dans différentes conditions (avec/sans radiateur, dans un endroit clos...).

Tests à réaliser :

- Sans ventilation :

À l'air libre

| Avec radiateur | Sans Radiateur
Cadence | 25 | 50 | 75 | 100 | 25 | 50 | 75 | 100
Cpu
Carte graphique
Carte réseau
Dans un boîtier
Cpu
Carte graphique
Carte réseau

- Avec ventilation :

À l'air libre

| Avec radiateur | Sans Radiateur
Cadence | 25 | 50 | 75 | 100 | 25 | 50 | 75 | 100
Cpu
Carte graphique
Carte réseau
Dans un boîtier
Cpu
Carte graphique
Carte réseau

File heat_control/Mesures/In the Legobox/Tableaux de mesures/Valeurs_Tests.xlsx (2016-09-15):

CPU % | 0.00 | 25.00 | 50.00 | 75.00 | 100.00
P1 | 27.20 | 32.60 | 35.80 | 37.30 | 41.20 | Disposition : 70 ar out, 120 dev in
P1 | 26.10 | 29.90 | 31.20 | 33.60 | 35.80
Capteur | 24.00 | 24.00 | 24.00 | 24.00 | 24.00
P2 | 30.44 | 34.70 | 37.90 | 40.10 | 44.40 | Disposition : 120 ar out, 80 dev in
P2 | 26.60 | 30.40 | 32.60 | 34.50 | 37.90
Capteur | 24.00 | 24.00 | 24.00 | 24.00 | 24.00
P3 | 30.40 | 35.20 | 39.50 | 43.30 | 46.00 | Disposition:120 ar out, 70 dev in
P3 | 28.80 | 31.50 | 33.10 | 35.80 | 39.00
Capteur | 23.00 | 23.00 | 23.00 | 23.00 | 23.00
P4 | 28.80 | 34.20 | 37.90 | 41.20 | 44.40 | Disposition : 70 ar out, 70 dev in
P4 | 26.60 | 29.90 | 32.60 | 35.80 | 39.00
Capteur | 23.00 | 23.00 | 23.00 | 23.00 | 23.00
P5 | 28.80 | 33.60 | 36.30 | 40.10 | 41.20 | Disposition : 120 av in, 80 ar out
P5 | 26.10 | 29.30 | 31.50 | 34.70 | 36.90
Capteur | 24.00 | 24.00 | 24.00 | 24.00 | 24.00
P6 | 29.30 | 34.70 | 37.90 | 40.60 | 43.30 | Disposition : 70 des in, 120 dev out, 80 ar out
P6 | 27.20 | 30.90 | 33.10 | 35.80 | 37.90
Capteur | 25.00 | 25.00 | 25.00 | 25.00 | 25.00
P7 | 27.70 | 32.60 | 35.80 | 37.90 | 40.60 | Disposition : 80 dev in, 70 ar out, 120 des out
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

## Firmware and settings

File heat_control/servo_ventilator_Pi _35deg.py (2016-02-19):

#!/usr/bin/python
# -*- coding:Utf-8 -*-

import RPi.GPIO as GPIO
import time
import os # Module pour importer les sorties de commande système
GPIO.setmode(GPIO.BOARD) # On utilise la numérotation des gpio physique

TempMax = "45" # Temp max avant déclenchement led + ventilo (max 80 degrès...)
GPIO.setup(18, GPIO.OUT) # On confgure la pin 18 (GPIO24) en sortie.

Ventilo = 18 #pin18 (GPIO24) ou ventilo branché

while 1: #1 plus rapide que true
 cmdtemp = '/opt/vc/bin/vcgencmd measure_temp'  # On définit la commande a appeller pour rapatrier la temperature
 result = os.popen(cmdtemp).readline().strip() # On appelle la cmdtemp avec le module os
 temp = result.split('=')[1].split("'")[0] # Le résultat étant temp=xx.x'C on y supprime pr garder que le chiffre
 if temp < TempMax:
     print("Température inférieure")
     GPIO.output(Ventilo, False)
 else:
     print("Température supérieure, lancement ventilo")
     GPIO.output(Ventilo, True)
 time.sleep(5) # Rafraichissement ttes les 5 secondes

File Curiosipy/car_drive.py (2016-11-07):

import RPi.GPIO as GPIO
import time
import numpy as np
import os
import multiprocessing

GPIO.setwarnings(False)
GPIO.setmode(GPIO.BOARD)
GPIO.setup(12,GPIO.OUT)
GPIO.output(12,GPIO.HIGH)
GPIO.setup(11,GPIO.OUT)
GPIO.output(11,GPIO.HIGH)
GPIO.setup(8,GPIO.OUT)
GPIO.output(8,GPIO.HIGH)
GPIO.setup(7,GPIO.OUT)
GPIO.output(7,GPIO.HIGH)

def forward(direction):
    pin = 0
    
    if direction == "left":
        pin = 12
    elif direction == "right":
        pin = 11
        
    if pin == 0:
        GPIO.output(8,GPIO.LOW)
        print('Going forward')
    else :
        GPIO.output(pin,GPIO.LOW)
        GPIO.output(8,GPIO.LOW)
        print('Going forward and ' + direction)

def backward(direction):
    pin = 0
    
    if direction == "left":
        pin = 12
    elif direction == "right":
        pin = 11
        
    if pin == 0:
        GPIO.output(7,GPIO.LOW)
        print('Going backward')
    else :
        GPIO.output(pin,GPIO.LOW)
        GPIO.output(7,GPIO.LOW)
        print('Going backward and ' + direction)

def stop():
    GPIO.setmode(GPIO.BOARD)
    GPIO.setup(12,GPIO.OUT)
    GPIO.output(12,GPIO.HIGH)
    GPIO.setup(11,GPIO.OUT)
    GPIO.output(11,GPIO.HIGH)
    GPIO.setup(8,GPIO.OUT)
    GPIO.output(8,GPIO.HIGH)
    GPIO.setup(7,GPIO.OUT)
    GPIO.output(7,GPIO.HIGH)
    



def distance(direction):
    echo = 0
    trig = 0
    if direction == "front":
        echo = 5
        trig = 3
    elif direction == "back":
        echo = 16
        trig = 15
    elif direction == "left":
        echo = 21
        trig = 3
    elif direction == "right":
        echo = 22
        trig = 10
    else :
        return "Error, args are 'front','back','left' or 'right'"
    
    try:
        GPIO.setup(trig,GPIO.OUT)
        GPIO.output(trig,GPIO.HIGH)
        GPIO.setup(echo,GPIO.IN)
        GPIO.output(trig,False)
        
        while GPIO.input(echo) == 0:
            nosig = time.time()

        while GPIO.input(echo) == 1:
            sig = time.time()

        tl = sig - nosig

        distance = tl / 0.000058 #pour obtenir la mesure en cm

        GPIO.output(trig,GPIO.HIGH)
        return distance,sig
    except:
        distance = "error"
        GPIO.output(trig,GPIO.HIGH)
        return distance,0

""" TEST DIRECTION 
GPIO.setmode(GPIO.BOARD)
GPIO.setup(11,GPIO.OUT)
GPIO.setup(8,GPIO.OUT)
GPIO.setup(12,GPIO.OUT)
GPIO.output(8,GPIO.LOW)
time.sleep(3)
GPIO.output(12,GPIO.LOW)
time.sleep(3)
GPIO.output(12,GPIO.HIGH)
GPIO.output(11,GPIO.LOW)
time.sleep(3)
stop()"""

'''
M = np.zeros((1000,1000))
for i in range(23):
    for j in range(33):
        M[500-11+i][500-16+j]=2
print(M[500-11][500+16])
'''

''' ARRET A DETECTION DE LOBSTACLE '''
stop()
for i in range(3):
    d,t = distance("front")
    advanced = False
    forward(0)
    print(d)
    while d>20:
        advanced = True
        time.sleep(0.05)
        d,t = distance('front')
        print(d)
    stop()
    if advanced :
        backward(0)
        time.sleep(0.1)
        stop()


""" FONCTIONNEMENT CAPTEURS
cotes = ['front','back','left','right']
for d in cotes:
    for i in range(30):
        print(d+" : "+str(distance(d)))
"""
"""
V,D = [],[]
for i in range(10):
    d1,t1 = distance('front')
    forward(0)
    time.sleep(0.05)
    stop()
    d2,t2 = distance('front')
    V.append((d1-d2)/(t2-t1))
    D.append(d2-d1)
    time.sleep(5)

v = sum(V)/10
d = sum(D)/10
print('distance min ='+str(d),'vitesse ='+str(v))
"""

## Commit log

2016-02-25 Modification Et Ajout Photos
    Retournement des Esquisse, Redimmensionnement du Schéma, Ajout Photos
    Test Aujourd’hui
2016-02-28 Dossier pour la fabrication du boîtier
2016-02-28 Dossier pour la fabrication du boitier
2016-03-05 Ajout Rapport Et Redimmensionnement Photos
    Test De Consommation Raspberry Pi en Fonction Charge Processeur, Durée
    Panne EDF, Redimmensionnement Photos
2016-03-05 Fond d'écran pour la page
2016-03-12 Ce bug a énervé plus d'un codeur. Vous n'allez pas croire comment il a été corrigé.
    [handle_tasks_RPi.py]
2016-03-14 ok pour recevoir des commandes
2016-03-15 Personne n'avait jamais codé des fonctions comme celles-là. Personne.
2016-03-15 toutes les 20s git push -u RPi3500 master
2016-03-31 Avancées dans les tests thermiques
2016-04-02 Rename & Re-organization + MarkDownization
    Modification & organisation box_architecture
    Introduction détails solutions coulisses à billes
    Modification & organisation power_supply
    Formatage sous MarkDown des rapport power_supply
2016-04-03 Présentation Mi-Parcours Power Supply & 3D Modeling
    Upload de Présentation Mi Parcours
    Upload ScreenShots Vues 3D avec Coulisses à Billes
2016-04-03 Diagrammes de comparaison
2016-04-04 Caractéristiques Composants, Boot & Shutdown Motif Batteries
    Caractéristiques des Composants en MD et PDF
    Courbes I=f(T)
    Rapport Boot & Shutdown MD
2016-04-04 Modification Boot & Shutdown
    Insertion Courbes et Rapport PDF
2016-05-01 Fetching Box Temperature
2016-05-24 relay update
2016-05-31 long messages bug fixed
    [handle_tasks_RPi.py]
2016-05-31 How a tsunami of graphics begins
    [Valeurs_Tests.xlsx]
2016-06-01 Working on Buttons
2016-06-01 Adafruit for William and new graphics
    [Evolution_temperature.xlsx, Valeurs_Tests.xlsx]
2016-06-02 Buttons change colors
2016-06-05 Presentation & Modélisation 3D
    [39-220-400.SLDASM, 39-220-400_01.SLDPRT, 39-220-400_02.SLDPRT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]
2016-06-06 display fixes and execution time mesures
    [temps_de_traitement_commandes.ods]
2016-06-12 heat_control_sysml sent
2016-06-15 Preparing presentation
    [Evolution_temperature.xlsx, Valeurs_Tests.xlsx]
2016-06-16 Presentation ready
    [Valeurs_Tests.xlsx]
2016-06-16 TIPE powerpoint finished
2016-07-08 Use of maps api and new databases
    [pop_arrondissements_grdesvilles_2013.xls, superficie_regions.xls]
2016-07-24 Created Adamant Algo note-giver and graphic result
    [activite_ar.xls, activite_qu.xls, dep13.xls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]
2016-07-31 Set up places and square meter prices data storage
    [Aix-en-Provence_places.csv, Allauch_places.csv, Alleins_places.csv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]
2016-09-04 Tableau des achats
    [Finances.xlsx]
2016-11-07 New car driver code
